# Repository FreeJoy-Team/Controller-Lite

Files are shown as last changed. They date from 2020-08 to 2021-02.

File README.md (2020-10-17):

# Controller-Lite

FreeJoy Controller Lite is a replacement for BluePill board designed specially for joystick devices applications.

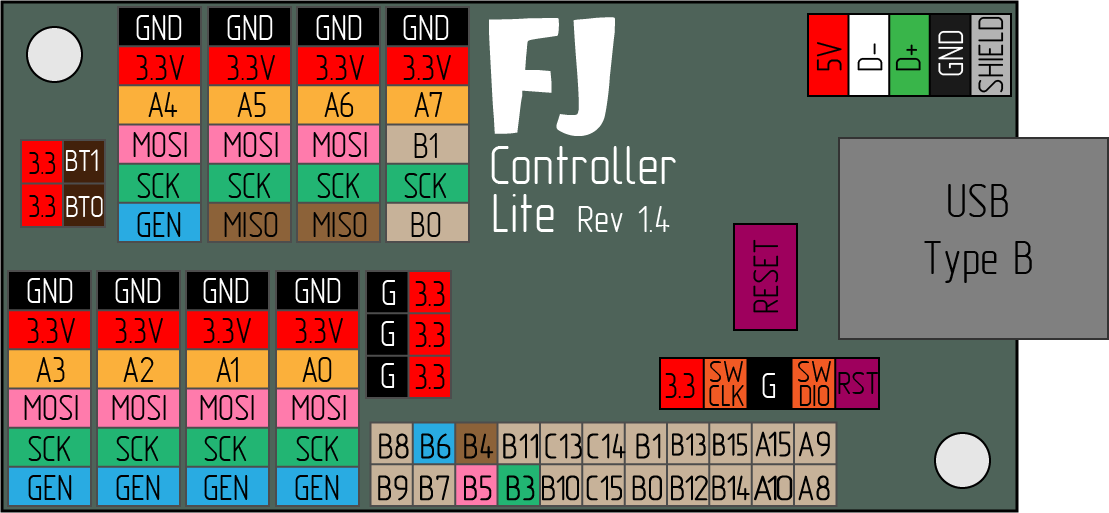
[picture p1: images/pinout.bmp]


### Main features of the controller PCB:

* Reliable USB Type B connector
* Optional JST PH-2.0 connector for USB cable
* ESD protection
* Convenient JST PH-2.0 connectors for external periphery
* Analog supply filtering
* Embedded pull-up resistors for I2C data lines and TLE501x data line (pull-up can be disabled by cutting a bridge)
* 22 I/O pins
* 8 connectors for analog axes, digital sensors, shift registers
* Additional VCC (3.3V) and GND pins
* 2 LEDs (power indicator and user-defined)
* Reset button
* 2 mounting holes D=3mm
* PCB dimentions 30x60mm (excluding USB Type B connector)

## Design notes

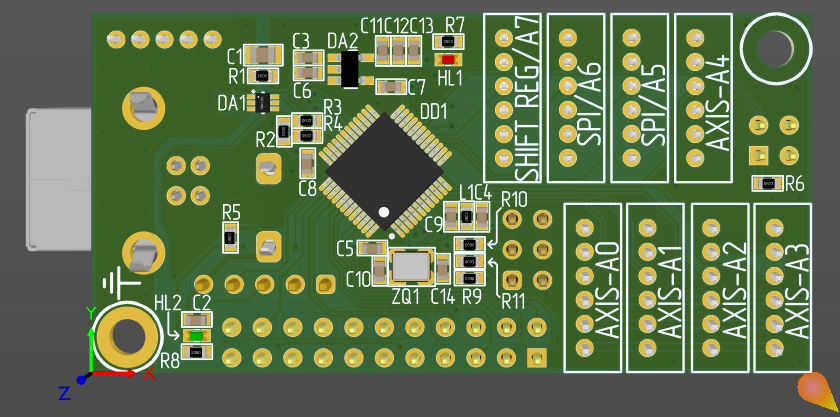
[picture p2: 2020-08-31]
images/back.png

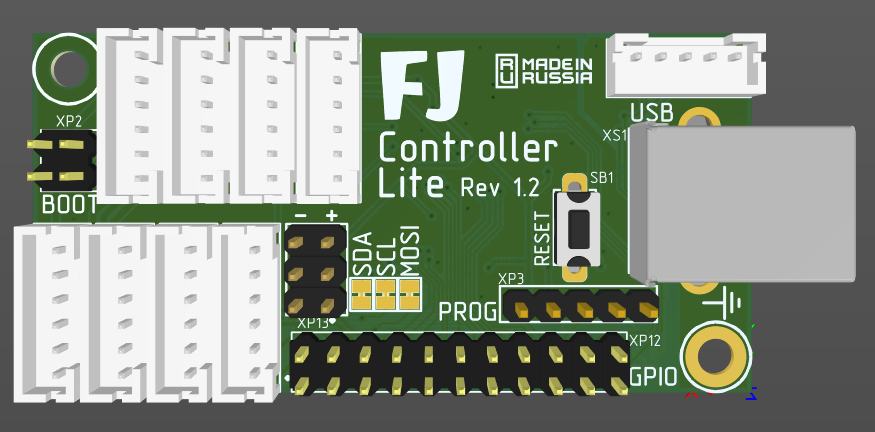
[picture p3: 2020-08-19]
images/front.png

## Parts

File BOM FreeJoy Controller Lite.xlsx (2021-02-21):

Designator | Description | Comment | Quantity
C1 | 4700pF ± 5%, 250V, X7R, SMD 0805 | 4.7nF 250V | 1
C2, C5, C6, C7, C8, C9, C12 | 0.1uF ± 10%, 25V, X7R, SMD 0603 | 100nF | 7
C3, C4, C11 | 1uF ± 10%, 16V, X7R, SMD 0603 | 1uF | 3
C10, C13, C14 | 22pF ± 5%, 50V, NPO, SMD 0603 | 22pF | 3
DA1 | ESR protection IC, USBLC6-2P6, SOT666 | USBLC6-2P6 | 1
DA2 | LDO voltage regulator, LP5907MFX-3.3, SOT23-5 | LP5907MFX-3.3 | 1
DD1 | MCU, STM32F103C8T6, LQFP48 | STM32F103C8T6 | 1
HL1 | KP-1608SRC, LED red, SMD 0603 | KP-1608SRC | 1
HL2 | KP-1608SGC, LED green, SMD 0603 | KP-1608SGC | 1
L1 | BLM18HG102SN1D, SMD 0603 | Ferrite bead, BLM18HG102SN1D | 1
R1 | 1M ± 1%, SMD 0603 | 1M | 1
R2 | 1K5 ± 1%, SMD 0603 | 1K5 | 1
R3, R4 | 27R ± 1%, SMD 0603 | 27R | 2
R5, R6, R7, R8, R10, R11 | 4K7 ± 1%, SMD 0603 | 4K7 | 6
R9 | 1K ± 1%, SMD 0603 | 1К | 1
SB1 | DTS-32, 3.5x6mm, THT | Tact Switch 3.5x6mm THT | 1
XP1 | PH2.0-5P | USB PH2.0-5P | 1
XP2 | PLS-5 | PROG | 1
XP3 | PLD-4 | BOOT | 1
XP4, XP5, XP6, XP7, XP8, XP9, XP10, XP11 | PH2.0-6P | AXIS-A0, AXIS-A1, AXIS-A2, AXIS-A3, AXIS-A4, SPI/A5, SPI/A6, SHIFT REG/A7 | 8
XP12 | PLD-22 | GPIO | 1
XP13 | PLD-6 | SUPPLY | 1
XS1 | DS1099, USB Type B Socket | USB Type B | 1
ZQ1 | Crystal Resonator, 8MHz, KX-7T | KX-7T 8MHz | 1

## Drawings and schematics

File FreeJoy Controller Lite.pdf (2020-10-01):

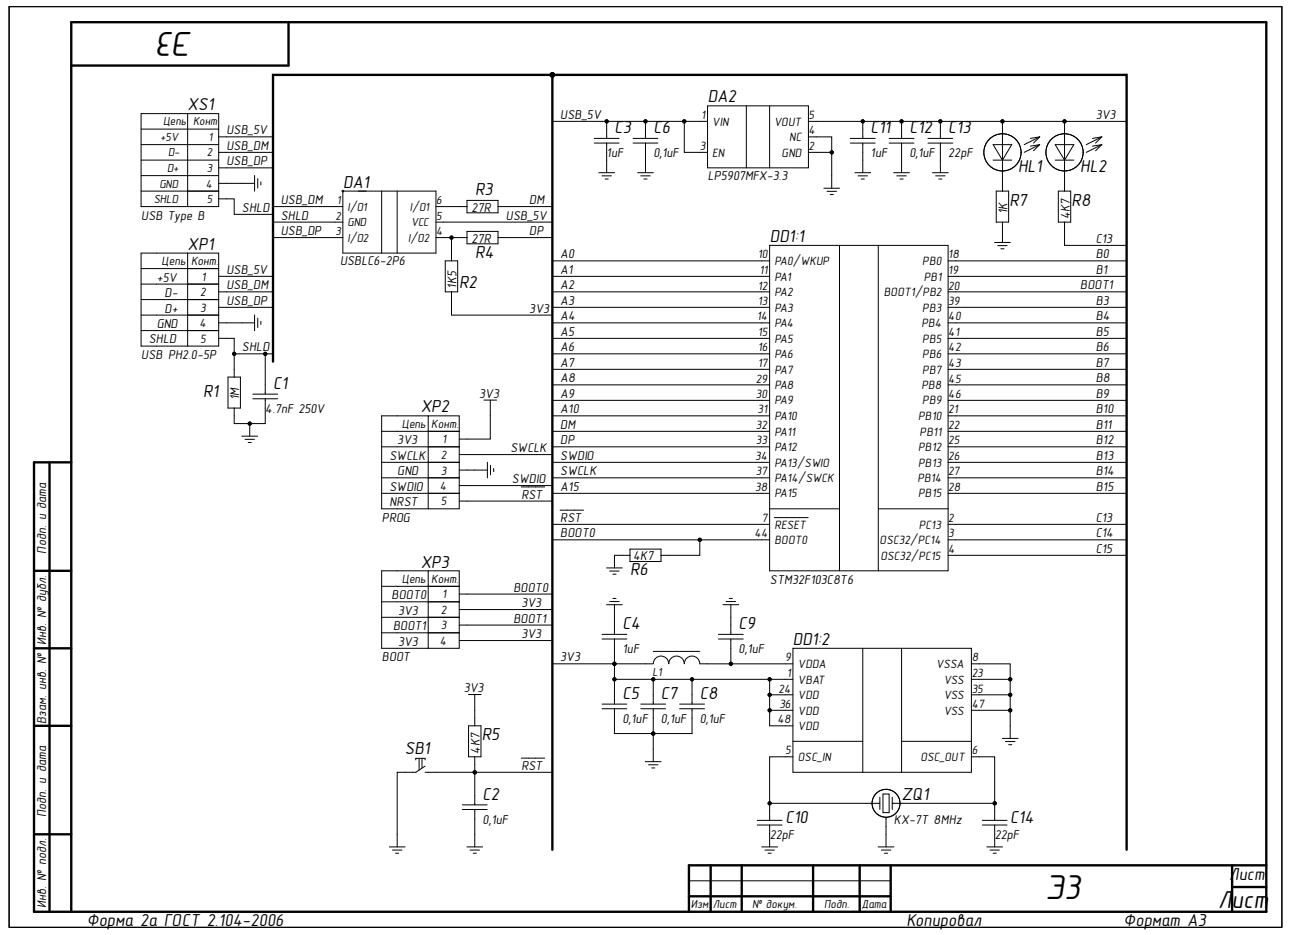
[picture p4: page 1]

Цепь | Конт
+5V | 1
D- | 2
D+ | 3
GND | 4

EN 3 | | VOUT | 5 VIN 1

Цепь | Конт.

Инв. № подл. Подп. и дата Взам. инв. № Инв. № дубл. Подп. и дата

BOOT0 | 1
3V3 | 2
BOOT1 | 3
3V3 | 4

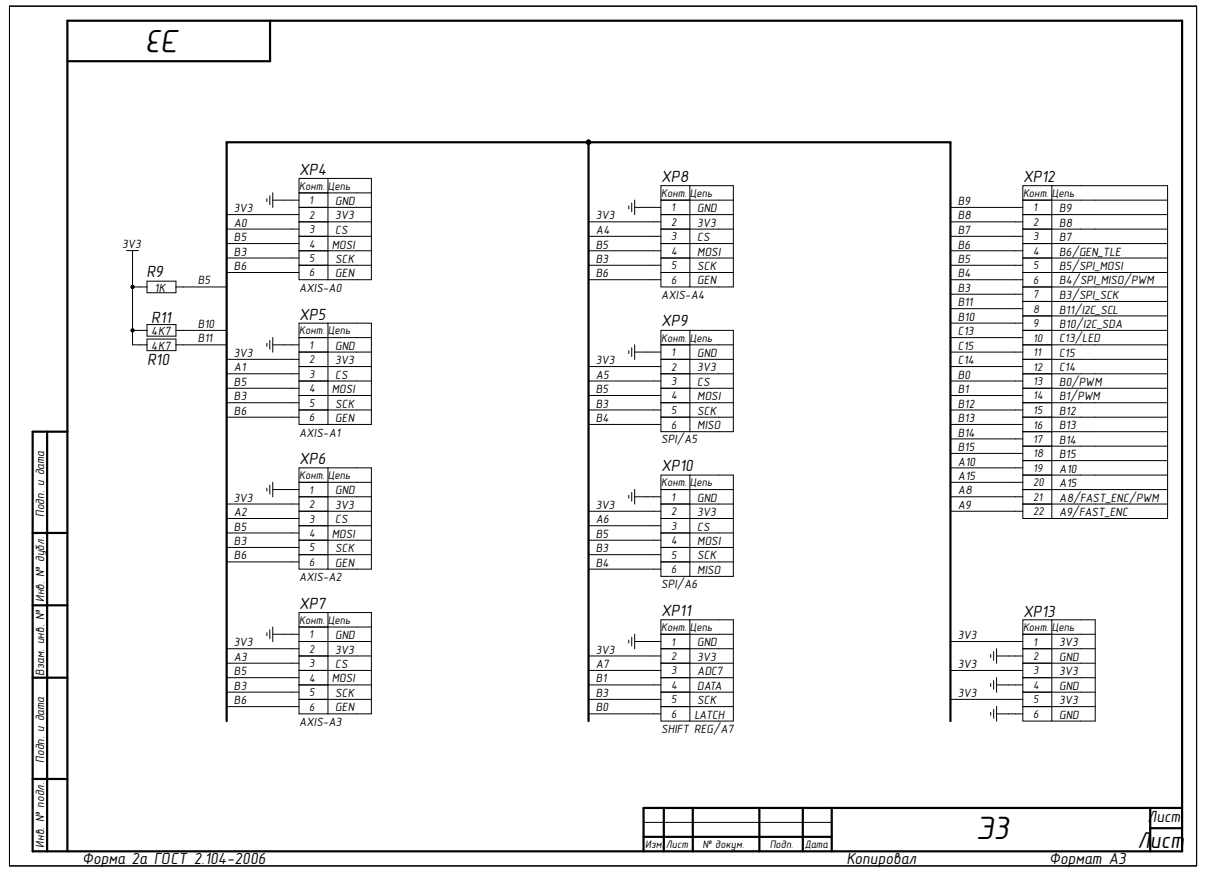
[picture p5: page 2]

XP4 | XP8
Конт . | Цепь

3V3 GND

B 1 1/I2C_SCL
10/I2C_SD B A

17 | B 1 4
18 | B 1 5
A1 0

Инв. № подл. Подп. и дата Взам. инв. № Инв. № дубл. Подп. и дата

Item # | Designator | Description | Comment | Quantity
1 | C1 | 4700pF ± 5%, 250V, X7R, SMD 0805 | 4.7nF 250V | 1
2 | C2, C5, C6, C7, C8, C9, C12 | 0.1uF ± 10%, 25V, X7R, SMD 0603 | 100nF | 7
3 | C3, C4, C11 | 1uF ± 10%, 16V, X7R, SMD 0603 | 1uF | 3
4 | C10, C13, C14 | 22pF ± 5%, 50V, NPO, SMD 0603 | 22pF | 3
5 | DA1 | ESR protection IC, USBLC6-2P6, SOT666 | USBLC6-2P6 | 1
6 | DA2 | LDO voltage regulator, LP5907MFX-3.3, SOT23-5 | LP5907MFX-3.3 | 1
7 | DD1 | MCU, STM32F103C8T6, LQFP48 | STM32F103C8T6 | 1
8 | HL1 | KP-1608SRC, LED red, SMD 0603 | KP-1608SRC | 1
9 | HL2 | KP-1608SGC, LED green, SMD 0603 | KP-1608SGC | 1
10 | L1 | BLM18HG102SN1D, SMD 0603 | Ferrite bead, BLM18HG102SN1D | 1
11 | R1 | 1M ± 1%, SMD 0603 | 1M | 1
12 | R2 | 1K5 ± 1%, SMD 0603 | 1K5 | 1
13 | R3, R4 | 27R ± 1%, SMD 0603 | 27R | 2
14 | R5, R6, R8, R10, R11 | 4K7 ± 1%, SMD 0603 | 4K7 | 5
15 | R7, R9 | 1K ± 1%, SMD 0603 | 1К | 2
16 | SB1 | DTS-32, 3.5x6mm, THT | Tact Switch 3.5x6mm THT | 1
17 | XP1 | PH2.0-5P | USB PH2.0-5P | 1
18 | XP2 | PLS-5 | PROG | 1
19 | XP3 | PLD-4 | BOOT | 1
20 | XP4 | PH2.0-6P | AXIS-A0 | 1
21 | XP5 | PH2.0-6P | AXIS-A1 | 1
22 | XP6 | PH2.0-6P | AXIS-A2 | 1
23 | XP7 | PH2.0-6P | AXIS-A3 | 1
24 | XP8 | PH2.0-6P | AXIS-A4 | 1
25 | XP9 | PH2.0-6P | SPI/A5 | 1
26 | XP10 | PH2.0-6P | SPI/A6 | 1
27 | XP11 | PH2.0-6P | SHIFT REG/A7 | 1
28 | XP12 | PLD-22 | GPIO | 1
29 | XP13 | PLD-6 | SUPPLY | 1
30 | XS1 | DS1099, USB Type B Socket | USB Type B | 1
31 | ZQ1 | Crystal Resonator, 8MHz, KX-7T | KX-7T 8MHz | 1

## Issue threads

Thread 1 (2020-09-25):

Encoders slow and skipping

blukk, 2020-09-25:
Several incremental encoders tried, with and without diodes. Played around with the settings in the configurator but rotary encoders like the common one used on the KY-040 board (desoldered from the board) work perfectly fine in for instance MMJOY if ON/OFF is selected. If only ON is selected it functions similar to that in Freejoy.

Once the rotary is turned fast it cannot keep up and doesn't translate into inputs. Once turned slow it works better but still skips steps. I tried 4 types of rotary encoders which all act similar.

Try for instance rotating a HDG bug in flightsimulator the full 360 degrees. Almost impossible or takes ages to get the full 360 degrees.

Is it a setting I miss?

BTW. Freejoy is awesome and thank you for sharing this!!

vostrenkov, 2020-09-27:
Hi,
I gonna check this out but skipping at fast rotation is because of filtering mechanical noise. It prevents encoder from going backwards while fast rotation.
Btw I can not fine ON/OFF options for encoders in MMJoy configurator, can you show me this? I'm not really familiar with that software

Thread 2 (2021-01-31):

Buy?

pipes80-collab, 2021-01-31:
I don't understand if it's just a project or if there is already a purchasable version?  Thanks in advance

vostrenkov, 2021-02-01:
Hi, it is not ready for purchasing yet. I'm still testing the board with different configurations and applications.
But there are all files allowing to order pcb and components by yourself
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

pipes80-collab, 2021-02-01:
I wait your product...I'm not able to make my self

pipes80-collab, 2021-02-16:
hello i need cpl file to order on jlcpcb

vostrenkov, 2021-02-16:
Hi,
I dont have cpl files for pcb assembly. Maybe I add this in the future but now it is supposed board to be assembled manually or somewhere at local production

pipes80-collab, 2021-02-16:
do you intend to assemble it by whoever produces the pcb? because on jlcpcb if you do not have the cpl file it is not possible but anyway I think I will try by myself ... thanks a lot and I hope to do a good job in honor of the good project which is freejoy

vostrenkov, 2021-02-16:
Usually I assemble my PCBs by myself. For the future of course I want to automate this process

FlisherOfatale, 2021-05-16:
If you want to use cheap provider like JLCPCB, most of them only offer cheap price for SMD on 1 side.
Design-wise, if all the SMD component are on 1 side, it can be smd assembled and only the trought-hole remain to be soldered manually.

vostrenkov, 2021-05-16:
I work in the organisation that have own pcb assembly production (both smd and tht). I gonna use it if I make a serial production because I can ask them to program and check boards after production

pipes80-collab, 2021-05-16:
Can know price sended in Italy?

vostrenkov, 2021-05-17:
I'm changing firmware now making current pcb design a bit deprecated. It still remains functional but not as flexible as is could be. The deal is B3 pin that wont be able to be used for shift registers and SPI sensors at the same time.
So I can't sell these boards until I make a new revision.
The target price is about 20-25$ per board excluding shipping from Russia

pipes80-collab, 2023-04-04:
What price have now shipping in Italy?

timgray, 2024-08-30:
there is a lot of interest in buying these, as blue pill clones are so flooding the market nobldy can buy working ones for freejoy easily.   I'd pay $15 each for these in kit form, $25 each assembled

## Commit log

2020-08-06 Rev 1.0
    [FreeJoy Controller Lite.PcbDoc, FreeJoy Controller Lite.PrjPcb, Sheet1.SchDoc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]
2020-08-06 Added gerber files
    [FreeJoy Controller Lite.PcbDoc, FreeJoy Controller Lite.PrjPcb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]
2020-08-06 Fixed ESR protection IC part number and 3D body
    [FreeJoy Controller Lite.PcbDoc, FreeJoy Controller Lite.PrjPcb, Sheet1.SchDoc]
2020-08-12 Rev 1.1
    [FreeJoy Controller Lite.PcbDoc, FreeJoy Controller Lite.PrjPcb, Sheet1.SchDoc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]
2020-08-13 Added cuttable traces for disabling/enabling pull-ups and some silk graphics
    [FreeJoy Controller Lite.PcbDoc, FreeJoy Controller Lite.PrjPcb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]
2020-08-19 Connectors moved to the other side from smd components
    [BOM FreeJoy Controller Lite.xlsx, FreeJoy Controller Lite.PcbDoc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]
2020-08-19 Image for readme
    [FreeJoy Controller Lite.PcbDoc, FreeJoy Controller Lite.PrjPcb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]
2020-08-31 Added pull-up resistor to NRST line, changed I2C and PWM functions mapping
    [BOM FreeJoy Controller Lite.xlsx, FreeJoy Controller Lite.PcbDoc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]
2020-08-31 Rev 1.3
    [FreeJoy Controller Lite.PcbDoc, FreeJoy Controller Lite.PrjPcb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]
2020-10-01 Fixed critical USB tracing error
    [BOM FreeJoy Controller Lite.xlsx, FreeJoy Controller Lite.PcbDoc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]
2020-10-15 Reduced LED resistors nominals
    [BOM FreeJoy Controller Lite.xlsx, FreeJoy Controller Lite.PcbDoc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]
2020-10-17 Added pinout image
    [FreeJoy Controller Lite.PcbDoc]
2021-02-21 BOM lines grouping
    [BOM FreeJoy Controller Lite.xlsx]
